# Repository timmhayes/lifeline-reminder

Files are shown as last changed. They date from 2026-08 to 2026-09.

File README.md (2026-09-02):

# Lifeline Check-In Monitor (ESP32-C6)

A compact safety-check reminder built for a Philips Lifeline wall-check device. This project uses an ESP32-C6 with an integrated LCD, a light sensor pointed at the Lifeline indicator LED, and a small LED strip to provide a visible daily reminder, detect a successful check-in, and log the event locally.

The device is intended as a non-invasive companion for a daily check-in routine and is designed to sit over the existing Lifeline unit without modifying the medical device itself.

This project was created for a parent living in an independent senior care facility. Each morning, the device reminds her to click the Lifeline button. If she forgets, the staff follow their normal daily check-in protocol and reach out to her to make sure she is okay. The local log is primarily for my own tracking and review, while the main purpose of the device is to provide a simple visual reminder that supports memory and daily routine without adding complexity.

For personal monitoring, the device’s local web interface is available on the device’s IP address on the local network at port 80. For example, if the board is assigned 192.168.1.55, the dashboard can be opened by visiting http://192.168.1.55/ and the log endpoint is http://192.168.1.55/log. This is intended for my own review of daily check-in status and not as a staff-facing system.

## Features

- Daily reminder state at a configured time (currently set for 5:00 AM)
- Optical detection of the Lifeline confirmation flash using a GM5539 photoresistor
- Visual confirmation with a green success state and an on-screen status update
- Wi-Fi connection and NTP time synchronization
- Local success logging to LittleFS
- Lightweight local web dashboard with a log endpoint
- 3D-printable enclosure concept for mounting over the Lifeline housing

## Demo

A short demo on how the device works is available on YouTube. The video shows the device in action, including the daily reminder and the check-in process.

YouTube video link (https://www.youtube.com/watch?v=AXnR_Kqfq6c)

## Current project status

This repository is a working prototype and is still evolving. The current implementation includes:

- Wi-Fi connection and backup SSID fallback
- Daily reset and alarm scheduling
- Sensor polling and threshold detection
- LED animation states for idle, alarm, and success
- LVGL-based status display
- Local log file persistence and simple web access

## Bill of Materials (BOM)

| Component | Description | Notes / Link |
| --- | --- | --- |
| Microcontroller / display | Waveshare ESP32-C6 1.47" display dev board | Main controller with onboard LCD and USB-C port. [Amazon](https://www.amazon.com/dp/B0F48GJD19) |
| Light sensor | 5 mm GM5539 LDR photoresistor | Used to detect the Lifeline indicator flash without modifying the device. [Amazon](https://www.amazon.com/dp/B01N7V536K) |
| Divider resistor | 10 kΩ resistor | Pairs with the photoresistor for an analog voltage divider. |
| Status LEDs | WS2812B 8-pixel RGB LED strip | Provides visible reminder and success indication. [Amazon](https://www.amazon.com/dp/B0D7CC469B) |
| External power port | USB-C female to 4-pin terminal cable | Optional cleaned-up external port. This was tested with the product linked here, but a 6-pin version is preferred for cleaner USB-C power handling. [Amazon](https://www.amazon.com/dp/B0D7CN4BTV) |
| Internal USB connector | USB-C 24-pin male plug solder module | Mates to the board internally. A 6-pin USB-C breakout is often cleaner and more reliable for power delivery. [Amazon](https://www.amazon.com/dp/B09WCQKSW1) |
| Hardware | M2 / M3 brass heat-set inserts and machine screws | Used for mounting the board and securing the enclosure. [Amazon](https://www.amazon.com/dp/B0FH4JQ3VB) |
| Enclosure | 3D-printed PLA or PETG housing | Custom mount designed to fit over the Lifeline housing. |

## Hardware overview

### Wiring & pinout

Circuit Diagram

### Recommended hardware

- Waveshare ESP32-C6 1.47-inch display dev board
- GM5539 photoresistor or similar LDR
- 10 kΩ resistor for the analog divider
- WS2812B 8-pixel RGB LED strip
- USB-C connection for power and programming
- Optional external USB port for clean enclosure integration

### Wiring summary

| Peripheral | ESP32-C6 pin | Notes |
| --- | --- | --- |
| NeoPixel data | GPIO 23 | WS2812B DIN |
| NeoPixel power | 5V / VBUS | LED strip supply |
| NeoPixel ground | GND | Common ground |
| Photoresistor | 3.3V | Sensor reference rail |
| Photoresistor ADC node | GPIO 1 | Reads analog voltage from divider |
| Divider resistor | GND / GPIO 1 | Forms voltage divider for light detection |

The pin configuration is defined in include/config.h.

## Important USB-C note

The external USB-C pigtail used for a clean panel connection commonly only exposes VBUS, GND, D+, and D-. That wiring does not include the required CC pull-down resistors for USB-C power negotiation.

> A 6-pin USB-C breakout or cable is preferred when possible because it includes the proper CC1/CC2 pull-down wiring needed for more reliable USB-C power delivery and safer operation with USB-C power sources.

For reliable power delivery:

- Use a USB-A to USB-C cable when powering from a standard USB wall adapter
- If direct USB-C to USB-C power is required, use a 6-pin USB-C breakout with proper 5.1 kΩ pull-downs on CC1/CC2, or add those resistors externally

## Enclosure and assembly

The [Lifeline enclosure.stl](./stl/Lifeline_enclosure.stl) file is located in the [stl](./stl) folder.

Recommended print settings:

- Material: PLA or PETG
- Layer height: 0.20 mm
- Infill: 15–20%
- Build plate: textured PEI recommended for a cleaner front finish

Assembly notes:

1. Mount the ESP32 display board in the enclosure.
2. Route the photoresistor so it points directly at the Lifeline indicator LED.
3. Block ambient room light around the sensor to reduce false positives.
4. Route power and data wiring cleanly through the enclosure.
5. Confirm the sensor sees the indicator flash in the intended operating environment.

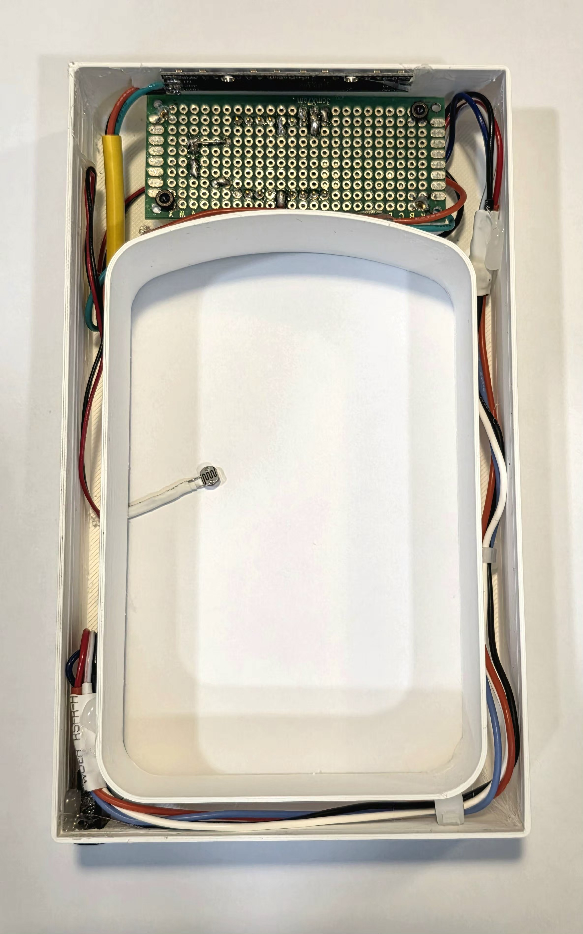
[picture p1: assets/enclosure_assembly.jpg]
Enclosure assembly

## Software setup

This project is built with PlatformIO in Visual Studio Code using the Arduino framework and LVGL.

### Required dependencies

The project uses the following libraries in platformio.ini:

- lvgl/lvgl@8.4.0
- adafruit/Adafruit NeoPixel@^1.12.3

### Configuration

1. Clone the repository.
2. Open the folder in VS Code with PlatformIO installed.
3. Edit include/config.h to set your Wi‑Fi credentials and time settings.
4. Build and upload the firmware to the ESP32-C6.

Example settings in include/config.h include:

- WIFI_SSID
- WIFI_PASSWORD
- WIFI_BACKUP_SSID
- WIFI_BACKUP_PASSWORD
- NTP_TIMEZONE
- NTP_SERVER_1
- NTP_SERVER_2
- ALARM_HOUR and ALARM_MINUTE
- sensor tuning values such as SENSOR_TRIGGER_DELTA and SENSOR_DEBOUNCE_MS

Important: do not commit real Wi‑Fi credentials to a public repository. Keep this file local or use environment-specific overrides before publishing.

## Build and upload

From the project root:

1. Open the project in VS Code
2. Ensure the PlatformIO extension is installed
3. Select the ESP32-C6 target
4. Build the project
5. Upload to the connected board
6. Watch the serial monitor for setup and calibration output

## Project structure

```text
.
├── assets/                 # photos, diagrams, related media
├── include/                # project headers and configuration
│   ├── app_state.h
│   ├── config.h            # Wi-Fi, time, and device tuning
│   ├── event_log.h
│   ├── led_status.h
│   ├── lv_conf.h
│   ├── sensor_monitor.h
│   ├── sensors.h
│   ├── ui_status.h
│   └── web_dashboard.h
├── src/                    # firmware implementation
│   ├── app_state.cpp
│   ├── Display_ST7789.cpp
│   ├── Display_ST7789.h
│   ├── event_log.cpp
│   ├── led_status.cpp
│   ├── LVGL_Driver.cpp
│   ├── LVGL_Driver.h
│   ├── main.cpp
│   ├── sensor_monitor.cpp
│   ├── sensors.cpp
│   ├── ui_status.cpp
│   └── web_dashboard.cpp
├── stl/                    # 3D-printable enclosure files
├── README.md
├── platformio.ini
└── .gitignore
```

## How it works

The firmware follows a simple daily safety-check flow:

1. The device connects to Wi‑Fi and syncs time using NTP.
2. The app state starts in IDLE.
3. At the configured alarm time, the system enters the ALARM_ACTIVE state.
4. The LED strip begins a visible reminder and the LCD prompts the user to click the check-in button.
5. The photoresistor samples the Lifeline indicator LED and looks for the expected flash pattern.
6. If the flash is detected in the correct state, the system enters SUCCESS and records the event.
7. The device prevents duplicate success entries for the same day until reset at midnight.

## Sensor tuning and calibration

The photoresistor logic is controlled by values in include/config.h. The main tuning values are:

- SENSOR_SAMPLE_INTERVAL_MS
- SENSOR_BASELINE_WINDOW
- SENSOR_WARMUP_SAMPLES
- SENSOR_TRIGGER_DELTA
- SENSOR_MIN_ABSOLUTE
- SENSOR_DEBOUNCE_MS

These values affect how sensitive the detector is to the Lifeline LED flash. In practice, the correct threshold depends on:

- room lighting
- sensor distance from the LED
- exact LED brightness on the Lifeline unit
- enclosure light leakage

It may be necessary to adjust these values for reliable operation in a different room or mounting position.

## Local dashboard

The device includes a lightweight local web server that exposes a simple dashboard and a log viewer on the local network:

- http://DEVICE_IP/ : basic status page
- http://DEVICE_IP/log : raw success log contents

This is intended for personal review of daily check-in history and can be accessed from any device on the same local Wi‑Fi network. The board listens on port 80, so the URL is simply the device IP with :80 implied in the browser.

Example:

- http://192.168.1.55/
- http://192.168.1.55/log

This is not intended as a public-facing service and is not meant for staff access at the facility.

## Troubleshooting

### Wi‑Fi does not connect

- Verify SSID and password in include/config.h
- Confirm the board is within range of the network
- Check the serial output for connection attempts

### Alarm does not trigger

- Confirm the timezone and time sync are working
- Check the ALARM_HOUR and ALARM_MINUTE values
- Inspect the app state logic in src/app_state.cpp

### Sensor never detects the press

- Check sensor alignment over the Lifeline indicator LED
- Reduce ambient light around the sensor
- Lower or raise the trigger thresholds in include/config.h
- Confirm the ADC input is reading a measurable change on flash

### Success log is empty

- Verify the device reaches the ALARM_ACTIVE state
- Confirm the sensor sees the expected flash
- Ensure the board has enough free space for LittleFS

## Safety and usage notes

This project is a prototype and should be treated as a personal assistance device, not a medical device.

- It is intended to support a daily reminder flow, not replace formal medical alert services
- The optical sensor depends on consistent mounting and room conditions
- The device should be tested in place before relying on it in a real care setting

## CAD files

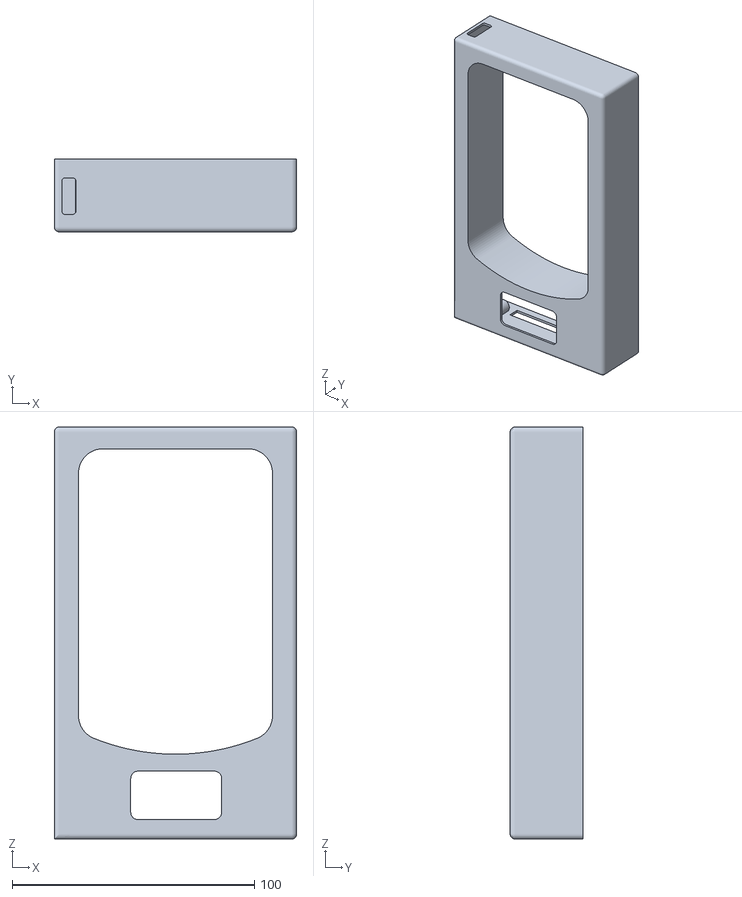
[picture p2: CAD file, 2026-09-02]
stl/Lifeline enclosure.stl
100.0 x 30.0 x 170.0

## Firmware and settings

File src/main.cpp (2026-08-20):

#include <WiFi.h>
#include <time.h>
#include <lvgl.h>
#include "lv_conf.h"
#include "LVGL_Driver.h"
#include "Display_ST7789.h"
#include "config.h"
#include "app_state.h"
#include "sensor_monitor.h"
#include "led_status.h"
#include "ui_status.h"
#include "event_log.h"
#include "web_dashboard.h"

lv_obj_t * main_label;
lv_obj_t * support_label;
AppState g_last_applied_state = AppState::IDLE;

void setupUI() {
    lv_obj_set_style_bg_color(lv_scr_act(), lv_color_hex(COLOR_BACKGROUND), 0);

    main_label = lv_label_create(lv_scr_act());
    lv_obj_set_style_text_font(main_label, TIME_LABEL_FONT, 0);
    lv_obj_set_style_text_color(main_label, lv_color_hex(COLOR_TIME_TEXT), 0);
    lv_label_set_text(main_label, "Syncing...");
    lv_obj_align(main_label, LV_ALIGN_CENTER, 0, TIME_LABEL_OFFSET_Y);

    support_label = lv_label_create(lv_scr_act());
    lv_obj_set_style_text_font(support_label, DATE_LABEL_FONT, 0);
    lv_obj_set_style_text_color(support_label, lv_color_hex(COLOR_DATE_TEXT), LV_PART_MAIN);
    lv_obj_set_style_bg_opa(support_label, LV_OPA_TRANSP, LV_PART_MAIN);
    lv_label_set_text(support_label, "");
    lv_obj_align(support_label, LV_ALIGN_CENTER, 0, DATE_LABEL_OFFSET_Y);
}

void connectWiFi() {
    const char* ssids[] = { WIFI_SSID, WIFI_BACKUP_SSID };
    const char* passwords[] = { WIFI_PASSWORD, WIFI_BACKUP_PASSWORD };

    while (WiFi.status() != WL_CONNECTED) {
        for (int attempt = 0; attempt < 2 && WiFi.status() != WL_CONNECTED; ++attempt) {
            if (ssids[attempt] == nullptr || ssids[attempt][0] == '\0') {
                continue;
            }

            lv_label_set_text(main_label, attempt == 0 ? "Connecting to WiFi..." : "Trying backup WiFi...");
            Serial.printf("Connecting with %s\n", ssids[attempt]);
            WiFi.begin(ssids[attempt], passwords[attempt]);

            const uint32_t start_time = millis();
            while (WiFi.status() != WL_CONNECTED && (millis() - start_time) < WIFI_CONNECT_ATTEMPT_MS) {
                delay(WIFI_CHECK_INTERVAL);
                Serial.print(".");
            }

            if (WiFi.status() == WL_CONNECTED) {
                break;
            }

            WiFi.disconnect(true);
            delay(WIFI_CHECK_INTERVAL);
        }

        if (WiFi.status() != WL_CONNECTED) {
            lv_label_set_text(main_label, "Retrying WiFi...");
        }
    }

    Serial.println(" Connected!");
}

void syncNetworkTime() {
    configTzTime(NTP_TIMEZONE, NTP_SERVER_1, NTP_SERVER_2);
}

void updateTimeDisplay(const tm& timeinfo) {
    static uint32_t last_time_update = 0;
    
    if (millis() - last_time_update > TIME_UPDATE_INTERVAL) {
        last_time_update = millis();

        char time_str[32];
        strftime(time_str, sizeof(time_str), TIME_FORMAT_STR, &timeinfo);

        char date_str[64];
        strftime(date_str, sizeof(date_str), DATE_FORMAT_STR, &timeinfo);

        UiStatus_UpdateClock(time_str, date_str);
    }
}

void setup() {
    Serial.begin(115200);

    LCD_Init(); 
    Set_Backlight(10);
    Lvgl_Init();

    setupUI();

    connectWiFi();
    syncNetworkTime();

    EventLog_Init();
    AppState_Init();
    SensorMonitor_Init();
    LedStatus_Init();

    UiStatus_Init(main_label, support_label);
    UiStatus_ApplyState(AppState_Get());
    LedStatus_SetState(AppState_Get());

    WebDashboard_Init();
}

void loop() {
    struct tm local_time;
    const bool has_time = getLocalTime(&local_time, GET_LOCAL_TIME_TIMEOUT);

    if (has_time) {
        AppState_ServiceSchedule(local_time);
        updateTimeDisplay(local_time);
    }

    const bool sensor_triggered = SensorMonitor_Poll();
    // EventLog_Clear();  // Clear the log file at the start of each loop iteration
    if (sensor_triggered) {
        if (AppState_Get() == AppState::ALARM_ACTIVE && AppState_TriggerSuccess()) {
            if (has_time) {
                EventLog_AppendSuccess(local_time);
            } else {
                struct tm fallback_time;
                if (getLocalTime(&fallback_time, GET_LOCAL_TIME_TIMEOUT)) {
                    EventLog_AppendSuccess(fallback_time);
                }
            }
        } else if (AppState_IsClickedToday()) {
            UiStatus_ShowAcknowledgement();
        }
    }

    const AppState current_state = AppState_Get();
    if (current_state != g_last_applied_state) {
        UiStatus_ApplyState(current_state);
        LedStatus_SetState(current_state);
        g_last_applied_state = current_state;
    }

    UiStatus_Service();
    LedStatus_Service();
    WebDashboard_Service();
    
    lv_tick_inc(LVGL_TICK_PERIOD); 
    lv_timer_handler();
    delay(LOOP_DELAY);
}

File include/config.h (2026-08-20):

#pragma once

// ============================================================================
// WiFi Configuration
// ============================================================================
#define WIFI_SSID       "ADD_SSID_HERE"
#define WIFI_PASSWORD   "ADD_PASSWORD_HERE"

// Optional backup WiFi credentials for a second location.
// Leave these empty if you only want to use the primary network.
#define WIFI_BACKUP_SSID      "ADD_SECONDARY_SSID_HERE"
#define WIFI_BACKUP_PASSWORD  "ADD_SECONDARY_PASSWORD_HERE"

// ============================================================================
// Display & UI Configuration
// ============================================================================
// Colors (RGB565 hex format)
#define COLOR_BACKGROUND  0x000000  // Black
#define COLOR_TIME_TEXT   0x00FFFF  // Cyan
#define COLOR_DATE_TEXT   0xFFFF00  // Yellow

// Dementia-friendly UI state colors (RGB565)
#define UI_ALARM_TEXT_COLOR    0xFFD0  // Warm amber
#define UI_SUCCESS_TEXT_COLOR  0x87F0  // Soft green
#define UI_SUPPORT_TEXT_COLOR  0xFFFF  // White

// Time Label Configuration
#define TIME_LABEL_OFFSET_Y  -20
#define TIME_LABEL_FONT      (&lv_font_montserrat_28)

// Date Label Configuration
#define DATE_LABEL_OFFSET_Y  10
#define DATE_LABEL_FONT      (&lv_font_montserrat_22)

// ============================================================================
// Time Synchronization Configuration
// ============================================================================
// NTP timezone string (EST/EDT with automatic DST)
#define NTP_TIMEZONE     "EST5EDT,M3.2.0,M11.1.0"
#define NTP_SERVER_1     "pool.ntp.org"
#define NTP_SERVER_2     "time.nist.gov"

// ============================================================================
// Timing Configuration
// ============================================================================
// WiFi connection check interval (milliseconds)
#define WIFI_CHECK_INTERVAL   500

// Maximum time spent on each WiFi credential before trying the next one (milliseconds)
#define WIFI_CONNECT_ATTEMPT_MS  15000

// Time display update interval (milliseconds)
#define TIME_UPDATE_INTERVAL  1000

// Brief acknowledgement shown when the button is clicked after the daily check-in is already complete.
#define UI_ACKNOWLEDGEMENT_MS  2000

// LVGL tick period (milliseconds)
#define LVGL_TICK_PERIOD      5

// Loop delay (milliseconds)
#define LOOP_DELAY            5

// getLocalTime timeout (deciseconds, 10 = 1 second)
#define GET_LOCAL_TIME_TIMEOUT  10

// ============================================================================
// Safety Check-In Hardware Configuration
// ============================================================================
#define PHOTORESISTOR_PIN          1
#define NEOPIXEL_PIN               23
#define NEOPIXEL_COUNT             8

// ============================================================================
// Daily State Schedule
// ============================================================================
#define RESET_HOUR                 0
#define RESET_MINUTE               0
#define ALARM_HOUR                 5
#define ALARM_MINUTE               0

// ============================================================================
// Photoresistor Flash Detection Tuning
// ============================================================================
#define SENSOR_SAMPLE_INTERVAL_MS  30
#define SENSOR_BASELINE_WINDOW     16
#define SENSOR_WARMUP_SAMPLES      20
#define SENSOR_TRIGGER_DELTA       500
#define SENSOR_MIN_ABSOLUTE        400
#define SENSOR_DEBOUNCE_MS         1500

// ============================================================================
// NeoPixel Animation Timing
// ============================================================================
#define LED_ANIM_INTERVAL_MS       40
#define LED_SUCCESS_ON_MS          8000

// Dementia-friendly UI animation timing
#define UI_PHRASE_ROTATE_MS        5000
#define UI_BREATH_STEP_MS          50
#define UI_BREATH_STEP_AMOUNT      6
#define UI_MIN_OPACITY             140
#define UI_MAX_OPACITY             255
#define UI_SUCCESS_GLOW_MS         1200

// Dementia-friendly NeoPixel comfort settings
#define LED_IDLE_BRIGHTNESS        8
#define LED_ACTIVE_BRIGHTNESS      32
#define LED_SUCCESS_BRIGHTNESS     40
#define LED_SUCCESS_CELEBRATE_MS   5000

// ============================================================================
// Local Log + Web Dashboard
// ============================================================================
#define SUCCESS_LOG_PATH           "/success_log.txt"
#define WEB_SERVER_PORT            80

// ============================================================================
// Time & Date Format Strings
// ============================================================================
#define TIME_FORMAT_STR   "%I:%M:%S %p"      // 12:34:56 PM
#define DATE_FORMAT_STR   "%A, %b %d, %Y"    // Monday, Jul 14, 2026

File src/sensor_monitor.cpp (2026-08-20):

#include "sensor_monitor.h"

#include <Arduino.h>

#include "config.h"

namespace {
int g_samples[SENSOR_BASELINE_WINDOW] = {0};
size_t g_sample_count = 0;
size_t g_next_index = 0;
long g_sum = 0;
uint32_t g_last_sample_ms = 0;
uint32_t g_last_trigger_ms = 0;
uint32_t g_total_samples = 0;
int g_last_raw = 0;
int g_last_baseline = 0;

void UpdateWindow(int sample) {
    if (g_sample_count < SENSOR_BASELINE_WINDOW) {
        g_samples[g_next_index] = sample;
        g_sum += sample;
        g_next_index = (g_next_index + 1) % SENSOR_BASELINE_WINDOW;
        g_sample_count++;
        return;
    }

    g_sum -= g_samples[g_next_index];
    g_samples[g_next_index] = sample;
    g_sum += sample;
    g_next_index = (g_next_index + 1) % SENSOR_BASELINE_WINDOW;
}
}  // namespace

void SensorMonitor_Init(void) {
    pinMode(PHOTORESISTOR_PIN, INPUT);
}

bool SensorMonitor_Poll(void) {
    const uint32_t now = millis();
    if ((now - g_last_sample_ms) < SENSOR_SAMPLE_INTERVAL_MS) {
        return false;
    }
    g_last_sample_ms = now;

    const int raw = analogRead(PHOTORESISTOR_PIN);
    // Serial.printf("SensorMonitor_Poll: raw=%d, baseline=%d\n", raw, g_last_baseline);
    g_last_raw = raw;
    // Serial.printf("SensorMonitor_Poll: raw=%d, baseline=%d, delta=%d\n", raw, g_last_baseline, raw - g_last_baseline);

    if (g_sample_count == 0) {
        UpdateWindow(raw);
        g_last_baseline = raw;
        g_total_samples++;
        return false;
    }

    g_last_baseline = static_cast<int>(g_sum / static_cast<long>(g_sample_count));
    const int delta = raw - g_last_baseline;

    const bool warmup_done = g_total_samples >= SENSOR_WARMUP_SAMPLES;
    const bool debounce_done = (now - g_last_trigger_ms) >= SENSOR_DEBOUNCE_MS;
    const bool above_floor = raw >= SENSOR_MIN_ABSOLUTE;
    const bool over_threshold = delta >= SENSOR_TRIGGER_DELTA;

    bool triggered = false;
    if (warmup_done && debounce_done && above_floor && over_threshold) {
        g_last_trigger_ms = now;
        triggered = true;
    }

    UpdateWindow(raw);
    g_total_samples++;

    return triggered;
}

int SensorMonitor_GetLastRaw(void) {
    return g_last_raw;
}

int SensorMonitor_GetLastBaseline(void) {
    return g_last_baseline;
}
